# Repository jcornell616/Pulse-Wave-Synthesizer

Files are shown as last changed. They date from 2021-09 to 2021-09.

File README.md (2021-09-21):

# Pulse-Wave Synthesizer

## Summary

The design implements a two-octave, 13 key synthesizer that outputs a square wave
with adjustable pulse width, volume, and gain. The keys are implemented using pushbuttons,
and the octave is selected using a switch. The octave being played is outputted to the LCD, and
an LED turns on if the signal is at risk of clipping. The sound is amplified to a speaker using the
LM386. 

## Design

The design uses a PIC18F47 microprocessor to process all digital inputs and outputs.
Two potentiometers are used to interface with the processor’s ADC, 13 pushbuttons and a
switch are digital inputs, and an LED, the LTC1661 DAC, and an LCD are digital outputs. The
board can be powered either by a 9V battery or by the DAD. An LM386 op-amp amplifies the
output of the LTC1661 to an 8 ohm speaker, with a third potentiometer used to control the
gain.

The software continuously checks which buttons are being pressed, which position the
switch is in, and the analog values of the potentiometers. These inputs are used to calculate the
output frequency, pulse width, and amplitude. The software ensures that the signal goes high
for ‘pulse-width’ amount of time and low for ‘period – pulse-width’ amount of time. When high,
the value written to the DAC is a value between 0x00 and 0xFF as controlled by an ADC input. If
the octave select changes, the new octave value (either 1 or 2) is outputted to the LCD.

## Bugs

The header for the snap-in programmer has a pin not connected to ground, and the data
pins for the 16x2 LCD were routed to the wrong pins. In both cases, the correct pins were wire
wrapped to the correct locations, and in the case for the LCD, the incorrect PCB traces were cut
with a knife to disconnect the incorrect pins. Additionally, a voltage divider was used instead of
a voltage regulator to step down the 9V battery to 5V, which is poor design practice. However, this
did not cause any problems in functionality of the design.

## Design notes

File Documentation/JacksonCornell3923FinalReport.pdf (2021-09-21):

Jackson Cornell
4/20/21
2554-1449

FINAL PROJECT – Report

Introduction
The design implements a two-octave, 13 key synthesizer that outputs a square wave with adjustable pulse width, volume, and gain. The keys are implemented using pushbuttons, and the octave is selected using a switch. The octave being played is outputted to the LCD, and an LED turns on if the signal is at risk of clipping. The sound is amplified to a speaker using the LM386.

Design
The design uses a PIC18F47 microprocessor to process all digital inputs and outputs. Two potentiometers are used to interface with the processor’s ADC, 13 pushbuttons and a switch are digital inputs, and an LED, the LTC1661 DAC, and an LCD are digital outputs. The board can be powered either by a 9V battery or by the DAD. An LM386 op-amp amplifies the output of the LTC1661 to an 8 ohm speaker, with a third potentiometer used to control the gain.

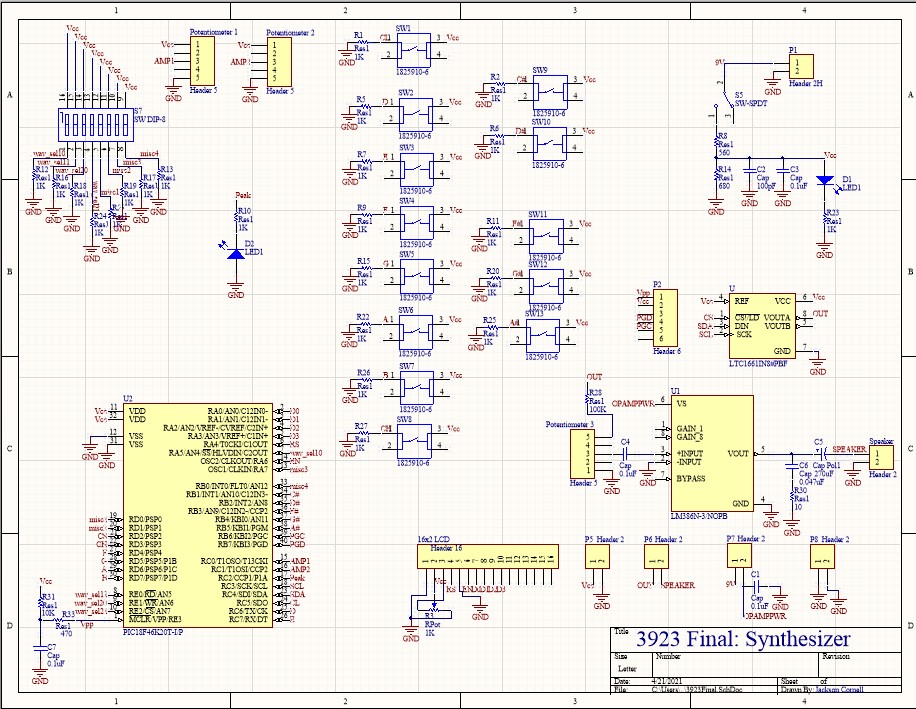
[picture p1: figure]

The software continuously checks which buttons are being pressed, which position the switch is in, and the analog values of the potentiometers. These inputs are used to calculate the output frequency, pulse width, and amplitude. The software ensures that the signal goes high for ‘pulse-width’ amount of time and low for ‘period – pulse-width’ amount of time. When high, the value written to the DAC is a value between 0x00 and 0xFF as controlled by an ADC input. If the octave select changes, the new octave value (either 1 or 2) is outputted to the LCD.

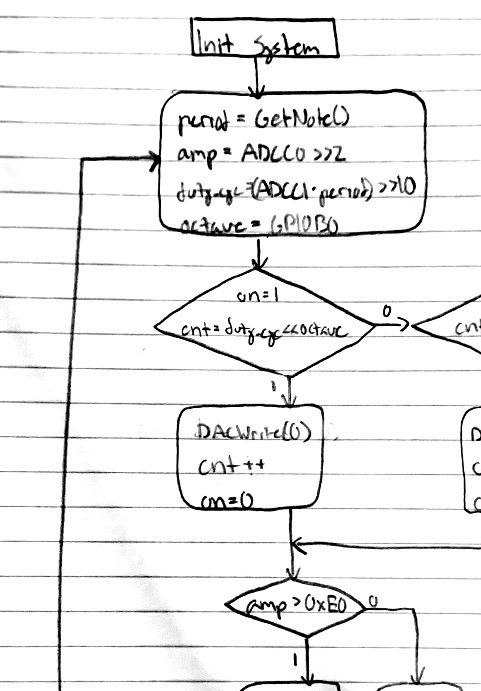
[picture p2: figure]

Materials
- 1 PIC18F47K40 Microcontroller - $2.75
- 1 16x2 LCD – $10.95

- 1 LTC1661 - $4.16
- 1 8 Ohm Speaker – 0.95
- 1 Switch Bank - $1.45
- 3 10K Potentiometers - $2.37
- 1 10K Trimmer - $0.85
- 4 0.1 uF capacitor - $0.40
- 1 100 pF capacitor - $0.10
- 1 0.047 uF capacitor - $0.10
- 1 270 uF capacitor - $0.90
- 1 10 Ohm Resistor – $0.10
- 1 470 Ohm Resistor – $0.10
- 1 560 Ohm Resistor – $0.10
- 1 680 Ohm Resistor – $0.10
- 23 1 KOhm Resistor – $2.30
- 1 10 KOhm Resistor – $0.10
- 1 100 KOhm Resistor – $0.10
- 1 SPST switch - $2.15
- 1 Red LED - $0.25
- 1 Green LED - $0.25
- 13 Tactile Pushbutton Switches - $1.30
- Header Pins - $1.50
- PCB Manufacturing - $9.40
- TOTAL - $42.73

Conclusion
For the most part, the design works as intended. There were, however, mistakes in the PCB. The header for the snap-in programmer has a pin not connected to ground, and the data pins for the 16x2 LCD were routed to the wrong pins. In both cases, the correct pins were wire wrapped to the correct locations, and in the case for the LCD, the incorrect PCB traces were cut with a knife to disconnect the incorrect pins. Additionally, a voltage divider was used instead of a voltage regulator to step down the 9V battery to 5V. However, this did not cause any problems in functionality of the design.

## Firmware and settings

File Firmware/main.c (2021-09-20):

/*
 * File:   main.c
 * Author: jacks
 *
 * Created on February 16, 2021, 1:19 PM
 */
#pragma config RSTOSC = HFINTOSC_64MHZ
#pragma config WDTE = OFF

#include <pic18f47k40.h>
#include <xc.h>

#define _XTAL_FREQ 64000000

#define CL          PORTCbits.RC5
#define C_          PORTBbits.RB1
#define D           PORTCbits.RC6
#define D_          PORTBbits.RB2
#define E           PORTDbits.RD4
#define F           PORTBbits.RB3
#define F_          PORTCbits.RC7
#define G           PORTDbits.RD5
#define G_          PORTBbits.RB4
#define A           PORTDbits.RD6
#define A_          PORTBbits.RB5
#define B           PORTDbits.RD7
#define CH          PORTDbits.RD3
#define peak        PORTCbits.RC2
#define octave_sel  PORTBbits.RB0


//constants
const char message1[] = "Jackson's Synth";
const char oct_mssg[] = "Octave: ";

//variables
volatile char high;
volatile char low;
volatile char on;
volatile char cnt;
volatile char amp;
volatile char period;
volatile char duty_cyc;
volatile char octave;
volatile char prev_octave;

//function declarations
void InitGPIO(void);
void dac_init(void);
void ADC_C0_init(void);
void ADC_C1_init(void);
void dac_write(char data);
int get_ADC_C0(void);
int get_ADC_C1(void);
void GetNote(void);
void AudioOut(void);
void lcd_command(char x);
void lcd_char(char x);
void lcd_init(void);
void print(const char str[], int size);
void PrintOctave(void);

/**  MAIN PROGRAM **/
void main(void) {
    
    //initialize peripherals
    InitGPIO();
    dac_init();
    ADC_C0_init();
    ADC_C1_init();
    lcd_init();
    
    //initialize variables
    high = 0;
    low = 1;
    on = 0;
    cnt = 0;
    amp = 0;
    period = 0;
    duty_cyc = 0;
    octave = 0;
    prev_octave = 0xFF;
    
    //print to LCD
    print(message1, 15);
    __delay_ms(2500);
    __delay_ms(2500);
    
    while(1) {\
        //read note
        GetNote();
        
        //read amplitude input
        amp = 0xFF - (char) (get_ADC_C0()>>2);
        duty_cyc = (char)((get_ADC_C1()*period)>>10);
        //read octave
        octave = octave_sel;
        
        //calculate audio out
        if ((on) && (cnt == duty_cyc<<octave)) {
            low = 1;
            on = 0;
            cnt++;
        }
        else if ((!on) && (cnt == period<<octave)) {
            high = 1;
            on = 1;
            cnt = 0;
        }
        else {
            cnt++;
        }
        AudioOut();
        
        //set LCD status
        if (octave != prev_octave) {
            PrintOctave();
            prev_octave = octave;
        }
    }
    
    return;
}

//functions

//configure GPIO pins
void InitGPIO(void) {
    //Set pins as digital
    ANSELBbits.ANSELB0 = 0;
    ANSELBbits.ANSELB1 = 0;
    ANSELBbits.ANSELB2 = 0;
    ANSELBbits.ANSELB3 = 0;
    ANSELBbits.ANSELB4 = 0;
    ANSELBbits.ANSELB5 = 0;
    ANSELCbits.ANSELC5 = 0;
    ANSELCbits.ANSELC6 = 0;
    ANSELCbits.ANSELC7 = 0;
    ANSELDbits.ANSELD3 = 0;
    ANSELDbits.ANSELD4 = 0;
    ANSELDbits.ANSELD5 = 0;
    ANSELDbits.ANSELD6 = 0;
    ANSELDbits.ANSELD7 = 0;
    ANSELEbits.ANSELE0 = 0;
    ANSELEbits.ANSELE1 = 0;
    ANSELEbits.ANSELE2 = 0;
    //Set pins as inputs
    TRISBbits.TRISB0 = 1;
    TRISBbits.TRISB1 = 1;
    TRISBbits.TRISB2 = 1;
    TRISBbits.TRISB3 = 1;
    TRISBbits.TRISB4 = 1;
    TRISBbits.TRISB5 = 1;
    TRISCbits.TRISC5 = 1;
    TRISCbits.TRISC6 = 1;
    TRISCbits.TRISC7 = 1;
    TRISDbits.TRISD3 = 1;
    TRISDbits.TRISD4 = 1;
    TRISDbits.TRISD5 = 1;
    TRISDbits.TRISD6 = 1;
    TRISDbits.TRISD7 = 1;
    TRISEbits.TRISE0 = 1;
    TRISEbits.TRISE1 = 1;
    TRISEbits.TRISE2 = 1;
    //Set pins as outputs
    TRISCbits.TRISC2 = 0;
}
//configure DAC
void dac_init(void) {
    ANSELCbits.ANSELC3 = 0; //Digital pin
    ANSELCbits.ANSELC4 = 0; //Digital pin
    TRISCbits.TRISC3 = 0; // set direction register
    TRISCbits.TRISC4 = 0;
    TRISDbits.TRISD2 = 0;
    RC3PPS = 0x0F; //map pins
    RC4PPS = 0x10;
    PORTDbits.RD2 = 1;   // enable to 1
    //SPI master
    SSP1CON1 = 0b101010;
    SSP1STATbits.CKE = 1; //data transition from active to idle
    //baud rate
    SSP1ADD = 71;
    PMD4 &= 0b01111;
}
//init C0 as ADC
void ADC_C0_init(void) {
    ADCON0bits.ADFM = 1; //right justify
    ADCON0bits.ADCS = 1; //FRC Clock
    TRISCbits.TRISC0 = 1; //Set RC0 to input
    ANSELCbits.ANSELC0 = 1; //Set RC0 to analog
    ADCON0bits.ADON = 1; //Turn ADC On
}
//init C1 as ADC
void ADC_C1_init(void) {
    ADCON0bits.ADFM = 1; //right justify
    ADCON0bits.ADCS = 1; //FRC Clock
    TRISCbits.TRISC1 = 1; //Set RC1 to input
    ANSELCbits.ANSELC1 = 1; //Set RC1 to analog
    ADCON0bits.ADON = 1; //Turn ADC On
}
//get ADC value
int get_ADC_C0(void) {
    ADPCH = 0b010000; //RC4 is Analog channel
    ADCON0bits.GO = 1; //Start conversion (ADGO = 1)
    while (ADCON0bits.GO); //Poll ADG0 bit
    char resultHigh = ADRESH; //Retrieve results
    char resultLow = ADRESL;
    return (int) (resultHigh<<8) | resultLow;
}
//get ADC value
int get_ADC_C1(void) {
    ADPCH = 0b010001; //RC4 is Analog channel
    ADCON0bits.GO = 1; //Start conversion (ADGO = 1)
    while (ADCON0bits.GO); //Poll ADG0 bit
    char resultHigh = ADRESH; //Retrieve results
    char resultLow = ADRESL;
    return (int) (resultHigh<<8) | resultLow;
}
//write serially to DAC
void dac_write(char data){
    char data_hi;
    char data_lo;
    //enable low
    PORTDbits.RD2 = 0;
    data_hi = 0xF0 | ((data>>4) & 0x0F);
    data_lo = 0xF0 & (data<<4);
    SSP1BUF = data_hi; //send data
    while(!PIR3bits.SSP1IF);
    PIR3bits.SSP1IF = 0;
    SSP1BUF = data_lo;
    while(!PIR3bits.SSP1IF);
    PIR3bits.SSP1IF = 0;
    //enable high
    PORTDbits.RD2 = 1;
}
//set timer based off note being played
void GetNote(void) {
    if (CH) {
        period = 23;
    }
    else if (B) {
        period = 24;    
    }
    else if (A_) {
        period = 25;    
    }
    else if (A) {
        period = 27;    
    }
    else if (G_) {
        period = 28;    
    }
    else if (G) {
        period = 30;
    }
    else if (F_) {
        period = 35;    
    }
    else if (F) {
        period = 31;    
    }
    else if (E) {
        period = 33;    
    }
    else if (D_) {
        period = 37;    
    }
    else if (D) {
        period = 39;    
    }
    else if (C_) {
        period = 42;    
    }
    else if (CL) {
        period = 44;    
    }
    else {
        period = 255;
    }
}
//calculate audio out
void AudioOut(void) {
    //INTCONbits.GIE = 0;
    if (high) {
        if (period != 255) {
            dac_write(amp);
        }
        if ((amp > 0xF0) && (period != 255)) {
            peak = 1;
        }
        else {
            peak = 0;
        }
        high = 0;
    }
    else if (low) {
        dac_write(0);
        low = 0;
    }
}
//send command to LCD
void lcd_command(char x){
    char temp;
    TRISAbits.TRISA0 = 0;
    TRISAbits.TRISA1 = 0;
    TRISAbits.TRISA2 = 0;
    TRISAbits.TRISA3 = 0;
    TRISAbits.TRISA4 = 0;
    TRISAbits.TRISA6 = 0;
    temp = x;
    PORTA = 0;
    __delay_ms(5);
    x = x >>4;
    x = x & 0xF;
    x = x | 0x40;
    PORTA = x;
    __delay_ms(5);
    x = x & 0xF;
    PORTA = x;
    __delay_ms(5);
    PORTA = 0;
    //__delay_ms(5);
    x = temp;
    x = x & 0xF;
    x = x | 0x40;
    PORTA = x;
    __delay_ms(5);
    x = x & 0xF;
    PORTA = x;
}
//send character to LCD
void lcd_char(char x){
    char temp;
    TRISAbits.TRISA0 = 0;
    TRISAbits.TRISA1 = 0;
    TRISAbits.TRISA2 = 0;
    TRISAbits.TRISA3 = 0;
    TRISAbits.TRISA4 = 0;
    TRISAbits.TRISA6 = 0;
    temp = x;
    PORTA = 0x10;
    __delay_ms(5);
    x = x >>4;
    x = x & 0xF;
    x = x | 0x50;
    PORTA = x;
    __delay_ms(5);
    x = x & 0x1F;
    PORTA = x;
    __delay_ms(5);
    PORTA = 0x10;
    __delay_ms(5);
    x = temp;
    x = x & 0xF;
    x = x | 0x50;
    PORTA = x;
    __delay_ms(5);
    x = x & 0x1F;
    PORTA = x;
}
//initialize LCD
void lcd_init(void){
    lcd_command(0x33);
    lcd_command(0x32);
    lcd_command(0x2C);
    lcd_command(0x0C);
    lcd_command(0x01);
}
//print string to LCD
void print(const char str[], int size) {
    for (int i = 0; i < size; i++) {
        lcd_char(str[i]);
        lcd_command(0x06);
    }
}
//print octave
void PrintOctave(void) {
    char temp = !(octave) + 0x31;
    lcd_command(0x01);
    print(oct_mssg, 8);
    lcd_char(temp);
}
